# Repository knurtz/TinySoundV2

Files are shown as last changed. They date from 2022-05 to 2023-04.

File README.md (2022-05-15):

# TinySound V2
Version two of [TinySound](https://github.com/knurtz/TinySound), a miniature audio module with a 3W class-D audio amplifier.

Instead of an SD card slot as version one, this module features a micro-USB port and presents itself as a mass storage device. Sound files and config data can easily be uploaded from any computer that supports FAT12 file systems.

## Parts list

- RaspberryPi RP2040 microcontroller
- MAX98360 class-D audio amp with I2S interface
- 16 MB of onboard flash

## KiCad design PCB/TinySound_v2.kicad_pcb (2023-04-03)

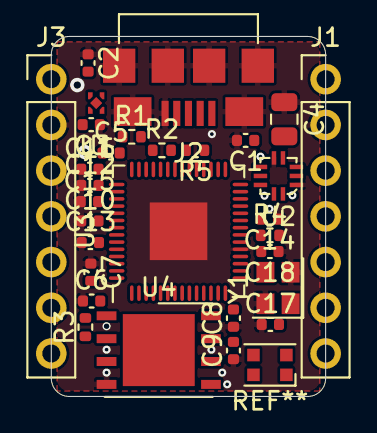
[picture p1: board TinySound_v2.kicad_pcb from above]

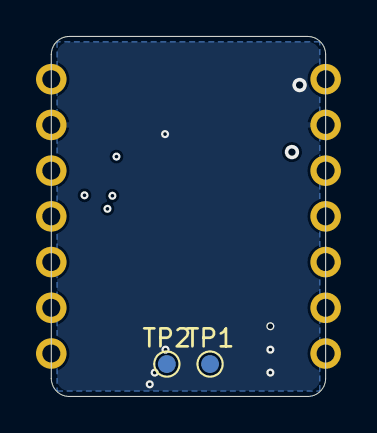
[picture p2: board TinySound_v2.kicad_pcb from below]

Board: 4 copper layers, 15.2 x 20.0 mm, 32 parts (2 on the bottom side), 33 nets, no tracks yet.

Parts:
C1, C5, C6, C7, C8, C9, C10, C13, C14, C16: 100n; C_0402_1005Metric
C2, C3, C12, C15: 1u; C_0402_1005Metric
C4: 10u; C_0805_2012Metric
C17, C18: 27p; C_0402_1005Metric
J1, J3: Conn_01x07; PinHeader_1x07_P2.54mm_Vertical
J2: USB_B_Micro; USB_Micro-B_Amphenol_10104110_Horizontal
R1, R2: 27R; R_0402_1005Metric
R3, R4: 1k; R_0402_1005Metric
R5: 10k; R_0402_1005Metric
TP1, TP2: TestPoint; TestPoint_Pad_D1.0mm
U1: MIC5504-3.3YMT; OnSemi_XDFN4-1EP_1.0x1.0mm_EP0.52x0.52mm
U2: MAX98360AEFB+T; FC2QFN-10
U3: RP2040; QFN-56_EP_7x7_Pitch0.4mm
U4: W25Q128JVS; DFN-8-1EP_6x5mm_P1.27mm_EP4x4mm
Y1: 12M; Crystal_SMD_2520-4Pin_2.5x2.0mm

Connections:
+3V3: C3.2, C5.2, C6.2, C7.2, C8.2, C9.2, C10.2, C12.2, C16.2, J3.1, R5.2, U1.1 (VOUT), U3.1 (IOVDD), U3.10 (IOVDD), U3.22 (IOVDD), U3.33 (IOVDD), U3.42 (IOVDD), U3.43 (ADC_AVDD), U3.44 (VREG_VIN), U3.48 (USB_VDD), U3.49 (IOVDD), U4.8 (VCC)
+5V: C1.1, C2.2, C4.2, J1.1, J2.1 (VBUS), U1.4 (VIN), U2.4 (VDD)
/+1V1: C13.2, C14.2, C15.2, U3.23 (DVDD), U3.45 (VREG_VOUT), U3.50 (DVDD)
/AU_BCLK: U2.8 (DAI2), U3.36 (GPIO24)
/AU_DIN: U2.10 (DAI1), U3.34 (GPIO22)
/AU_EN: U2.6 (EN), U3.37 (GPIO25)
/AU_LRCLK: U2.9 (DAI0), U3.35 (GPIO23)
/GPIO1: J1.5, U3.30 (GPIO19)
/GPIO2: J1.6, U3.29 (GPIO18)
/GPIO3: J1.7, U3.40 (GPIO28/ADC2)
/GPIO4: J3.4, U3.8 (GPIO6)
/GPIO5: J3.3, U3.5 (GPIO3)
/OUTN: J1.3, U2.3 (OUTN)
/OUTP: J1.4, U2.2 (OUTP)
/QSPI_SCLK: U3.52 (QSPI_SCLK), U4.6 (CLK)
/QSPI_SD0: U3.53 (QSPI_SD0), U4.5 (DI(IO0))
/QSPI_SD1: U3.55 (QSPI_SD1), U4.2 (DO(IO1))
/QSPI_SD2: U3.54 (QSPI_SD2), U4.3 (IO2)
/QSPI_SD3: U3.51 (QSPI_SD3), U4.7 (IO3)
/QSPI_SS: R3.2, U3.56 (QSPI_SS_N), U4.1 (~CS)
/RUN: J3.7, R5.1, U3.26 (RUN)
/SWCLK: TP2.1, U3.24 (SWCLK)
/SWDIO: TP1.1, U3.25 (SWDIO)
/UART_RX: J3.6, U3.7 (GPIO5)
/UART_TX: J3.5, U3.6 (GPIO4)
/USB_DM: R2.1, U3.46 (USB_DM)
/USB_DP: R1.1, U3.47 (USB_DP)
/XIN: C18.2, U3.20 (XIN), Y1.3
/XOUT: R4.1, U3.21 (XOUT)
GND: C1.2, C2.1, C3.1, C4.1, C5.1, C6.1, C7.1, C8.1, C9.1, C10.1, C12.1, C13.1, C14.1, C15.1, C16.1, C17.1, C18.1, J1.2, J2.5 (GND), J2.6 (Shield), J3.2, U1.2 (GND), U1.5, U2.1 (GND), U2.5 (GND), U3.19 (TESTEN), U3.57 (GND), U4.4 (GND), Y1.2, Y1.4
unnamed: C17.2, R4.2, Y1.1
unnamed: J2.2 (D-), R2.2
unnamed: J2.3 (D+), R1.2

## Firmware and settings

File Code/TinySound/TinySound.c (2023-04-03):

#include <stdio.h>
#include <string.h>

#include "pico/stdlib.h"
#include "hardware/gpio.h"

#include "tusb.h"
#include "flash_functions.h"

#include "TS_shell.h"
#include "TS_audio.h"
#include "TS_fat.h"


#define LED_PIN         28
uint32_t next_blink_ms = 0;
uint16_t blink_interval_ms = 500;
uint16_t blink_interval_fast_ms = 200;

void blink(void)
{
    if (time_us_32() / 1000 > next_blink_ms)
    {
        next_blink_ms += Audio_IsPlaying() ? blink_interval_fast_ms : blink_interval_ms;
        gpio_put(LED_PIN, !gpio_get(LED_PIN));
    }
}


#define TRIGGER_PIN     5
#define TRIGGER_DELAY 10000      // us
uint32_t last_trigger = 0;      // us
uint8_t trigger_counter = 0;

void __isr __time_critical_func(trigger_callback)(uint gpio, uint32_t events)
{
    trigger_counter++;
    last_trigger = time_us_32();
}


char* tracklist[] =
    {
        "01.wav",
        "02.wav",
        "03.wav",
        "04.wav",
        "05.wav",
        "06.wav",
        "07.wav",
        "08.wav",
        "09.wav"
    };


int main()
{
    stdio_init_all();
    tusb_init();

    Shell_Init();
    Flash_Init();
    Audio_Init();

    // Init LED output
    gpio_init(LED_PIN);
    gpio_set_dir(LED_PIN, GPIO_OUT);

    // Init play trigger input
    gpio_init(TRIGGER_PIN);
    gpio_set_dir(TRIGGER_PIN, GPIO_IN);
    gpio_disable_pulls(TRIGGER_PIN);
    gpio_set_irq_enabled_with_callback(TRIGGER_PIN, GPIO_IRQ_EDGE_FALL, true, &trigger_callback);

    FAT_Init();

    while (true)
    {
        tud_task();
        Shell_CheckCommand();
        Flash_WriteCycle(false);
        Audio_CheckBuffer();
        
        if (trigger_counter && time_us_32() > last_trigger + TRIGGER_DELAY)
        {
            xprintf("Triggered %d times\n", trigger_counter);

            if (trigger_counter < count_of(tracklist));
                Audio_Play(tracklist[trigger_counter]);

            trigger_counter = 0;
        }

        blink();
    }

    return 0;
}


void _close(void) {}
void _lseek(void) {}

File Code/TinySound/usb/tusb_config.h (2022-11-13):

/*
 * The MIT License (MIT)
 *
 * Copyright (c) 2019 Ha Thach (tinyusb.org)
 *
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
 */

#ifndef _TUSB_CONFIG_H_
#define _TUSB_CONFIG_H_

#ifdef __cplusplus
 extern "C" {
#endif

//--------------------------------------------------------------------
// COMMON CONFIGURATION
//--------------------------------------------------------------------

// defined by board.mk
#ifndef CFG_TUSB_MCU
  #error CFG_TUSB_MCU must be defined
#endif

// RHPort number used for device can be defined by board.mk, default to port 0
#ifndef BOARD_DEVICE_RHPORT_NUM
  #define BOARD_DEVICE_RHPORT_NUM     0
#endif

// RHPort max operational speed can defined by board.mk
// Default to Highspeed for MCU with internal HighSpeed PHY (can be port specific), otherwise FullSpeed
#ifndef BOARD_DEVICE_RHPORT_SPEED
  #if (CFG_TUSB_MCU == OPT_MCU_LPC18XX || CFG_TUSB_MCU == OPT_MCU_LPC43XX || CFG_TUSB_MCU == OPT_MCU_MIMXRT10XX || \
       CFG_TUSB_MCU == OPT_MCU_NUC505  || CFG_TUSB_MCU == OPT_MCU_CXD56)
    #define BOARD_DEVICE_RHPORT_SPEED   OPT_MODE_HIGH_SPEED
  #else
    #define BOARD_DEVICE_RHPORT_SPEED   OPT_MODE_FULL_SPEED
  #endif
#endif

// Device mode with rhport and speed defined by board.mk
#if   BOARD_DEVICE_RHPORT_NUM == 0
  #define CFG_TUSB_RHPORT0_MODE     (OPT_MODE_DEVICE | BOARD_DEVICE_RHPORT_SPEED)
#elif BOARD_DEVICE_RHPORT_NUM == 1
  #define CFG_TUSB_RHPORT1_MODE     (OPT_MODE_DEVICE | BOARD_DEVICE_RHPORT_SPEED)
#else
  #error "Incorrect RHPort configuration"
#endif

// This example doesn't use an RTOS
#undef CFG_TUSB_OS
#define CFG_TUSB_OS               OPT_OS_NONE

// CFG_TUSB_DEBUG is defined by compiler in DEBUG build
// #define CFG_TUSB_DEBUG           0

/* USB DMA on some MCUs can only access a specific SRAM region with restriction on alignment.
 * Tinyusb use follows macros to declare transferring memory so that they can be put
 * into those specific section.
 * e.g
 * - CFG_TUSB_MEM SECTION : __attribute__ (( section(".usb_ram") ))
 * - CFG_TUSB_MEM_ALIGN   : __attribute__ ((aligned(4)))
 */
#ifndef CFG_TUSB_MEM_SECTION
#define CFG_TUSB_MEM_SECTION
#endif

#ifndef CFG_TUSB_MEM_ALIGN
#define CFG_TUSB_MEM_ALIGN          __attribute__ ((aligned(4)))
#endif

//--------------------------------------------------------------------
// DEVICE CONFIGURATION
//--------------------------------------------------------------------

#ifndef CFG_TUD_ENDPOINT0_SIZE
#define CFG_TUD_ENDPOINT0_SIZE    64
#endif

//------------- CLASS -------------//
#define CFG_TUD_CDC              1
#define CFG_TUD_MSC              1
#define CFG_TUD_HID              0
#define CFG_TUD_MIDI             0
#define CFG_TUD_VENDOR           0

// CDC FIFO size of TX and RX
#define CFG_TUD_CDC_RX_BUFSIZE   (TUD_OPT_HIGH_SPEED ? 512 : 64)
#define CFG_TUD_CDC_TX_BUFSIZE   (TUD_OPT_HIGH_SPEED ? 512 : 64)

// MSC Buffer size of Device Mass storage
#define CFG_TUD_MSC_EP_BUFSIZE   512

#ifdef __cplusplus
 }
#endif

#endif /* _TUSB_CONFIG_H_ */

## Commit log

2022-04-23 Copied project structure from TinySound v1
    [TinySound_v2.kicad_pcb, TinySound_v2.kicad_sch, TinySound_v2.sch]
2022-04-23 Added all components in schematic
    [TinySound_v2.kicad_sch]
2022-04-23 RP2040 power, flash, crystal and reset
    [TinySound_v2.kicad_sch]
2022-04-23 Finished first version of schematic
    [TinySound_v2.kicad_sch]
2022-04-23 Added footprints, annoted schematic
    [TinySound_v2.kicad_sch]
2022-05-15 Added first version of PCB
    [TinySound_v2.kicad_pcb, TinySound_v2.kicad_sch, TinySound_v2.sch]
2022-06-05 Added interactive BOM
2022-12-05 Disabled interrupts on flash access for safety reasons.
2022-12-07 Cleared round traces on PCB, added WS2812 in schematic
    [TinySound_v2.kicad_pcb, TinySound_v2.kicad_sch]
2022-12-13 Added FatFS with custom glue functions for mass storage access
2022-12-16 Mounting mass storage and folder tree works on device
2023-04-03 New component arrangement vor v2.1
    [TinySound_v2.kicad_pcb, TinySound_v2.kicad_sch]
2023-04-03 Moved components to better positions
    [TinySound_v2.kicad_pcb]
